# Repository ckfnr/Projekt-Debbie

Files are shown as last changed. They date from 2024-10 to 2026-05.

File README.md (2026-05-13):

# **Debbie**

<p align="center">
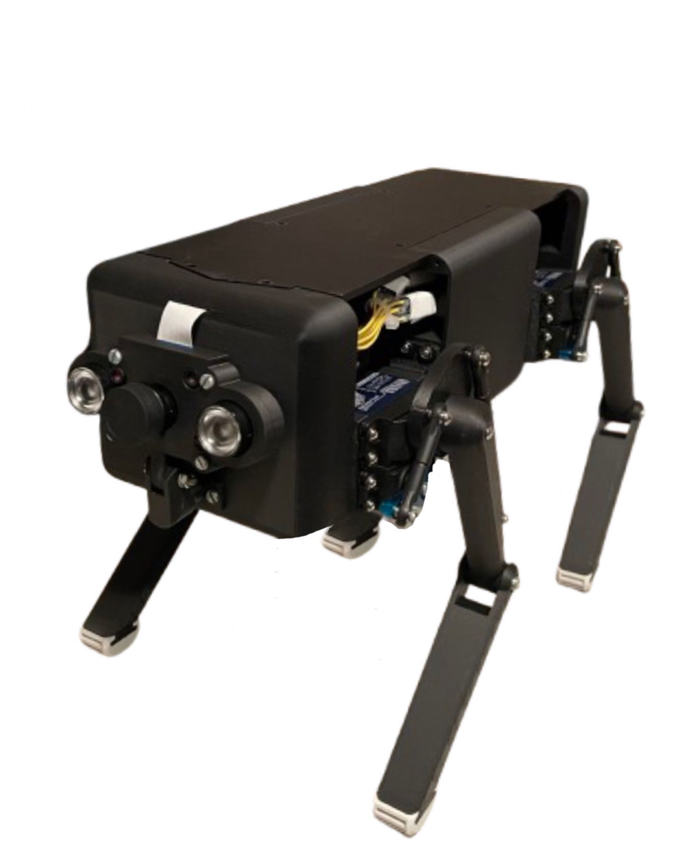
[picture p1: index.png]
  
</p>

## 📜 **Description**
_Debbie_ is a straightforward yet fascinating quadrupedal robot designed with simplicity in mind. Stay tuned for ongoing enhancements!<br>
💰Project sponsored by _The Schrack Technik Group_

## 📝 Incoming
- Detailed documentation
- Remote control

## ⚙️ Accessories
- [Remote Control](https://github.com/AJ-Holzer/Debbie-V1---Keyboard)

## 👀 Check out
### ⚙ Hardware-Development, assisting Programmer, Design & Organization:
- [Cesario Kufner](https://github.com/ckfnr)
### 💻 Programming:
- [AJ-Holzer](https://github.com/AJ-Holzer)
### Documentation & assisting in Design:
- [Louati Momen](https://github.com/louatimomen)
### Huge Shoutout to [Mr. Hühnchen](https://github.com/MrHuehnchen)! 🎉
A massive thank you to __Mr. Hühnchen__ for calculating __all the computations__ for Debbie!<br>
💡⚡

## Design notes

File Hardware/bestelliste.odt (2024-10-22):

Bestellliste

Servomotoren x 12

link: https://amzn.eu/d/aAuCnyE

preis: 290,28 euro

Akku x 9

link: https://www.conrad.at/de/p/eve-inr18650-33v-spezial-akku-18650-flat-top-hochstromfaehig-li-ion-3-6-v-3200-mah-2618353.html

preis: 1107,25 euro

Battery spot welder x 1

link: https://amzn.eu/d/flXxwCL

preis: 50.42 euro

Gyroskop-Sensor x 1

link: https://amzn.eu/d/5GvUgRg

preis: 9.06 euro

Google coral AI accelerator x 1

link: https://amzn.eu/d/iyRLuVV

preis: 91.70 euro

Raspberry 4b x1

link: https: https://amzn.eu/d/8mECIaa

preis: 86,71 euro

Raspberry pi Camera x1

link: https://nl.aliexpress.com/item/32881466491.html?spm=a2g0s.9042311.0.0.320c4c4dXaaHcX

preis: 11.59 euro

Schrauben-Set x1

link: https://amzn.eu/d/2u4cu5q

preis: 25.70 euro

PCB-protection circuit x1

link: https://amzn.eu/d/9HBHvqb

preis: 11.09 euro

Servo Driver x1

link: https://amzn.eu/d/9qbfp5R

preis: 7.04 euro

Rod ends x1

link: https://amzn.eu/d/5am6awO

preis: 16.66 euro

684ZZ Kugellager x2

link: https://amzn.eu/d/8TTudFz

preis: 11,06 euro

Servo Horn 25T x2

link: https://amzn.eu/d/a9BvvhE

preis: 24,38 euro

Schalter x1

link: https://www.soselectronic.com/de-de/products/marquardt/1830-3112-468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

preis: 3,33 euro

HDMI-Verlängerung x1

https://www.amazon.de/gp/product/B09PYWKCWW/ref=ppx_yo_dt_b_asin_title_o01_s00?ie=UTF8&th=1

preis: 10,07 euro

USB-Verlängerung x1

https://www.amazon.de/dp/B083Y2DR9Z?ref=ppx_yo2ov_dt_b_fed_asin_title

preis: 10,07 euro

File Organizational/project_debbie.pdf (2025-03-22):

## Project Debbie

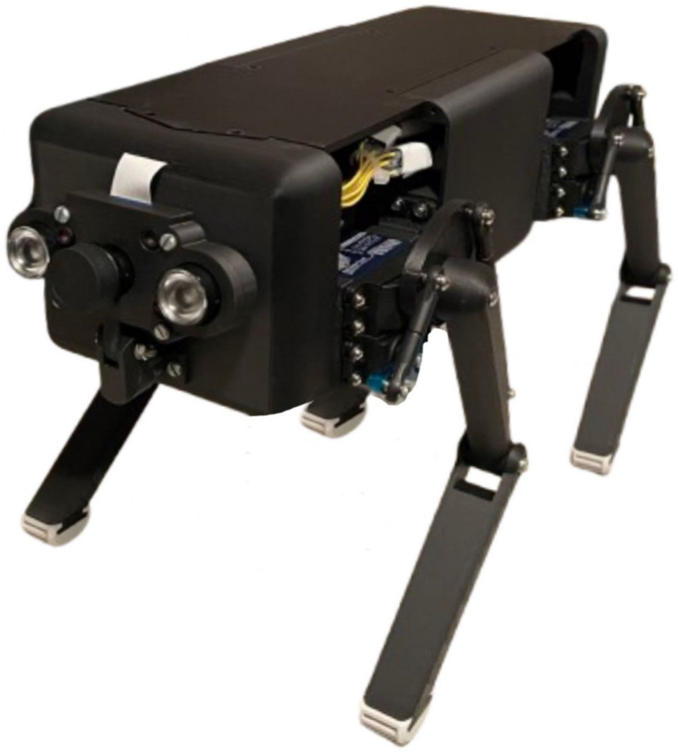
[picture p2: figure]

Cesario Kufner
Momen Louati
AJ Holzer
Prof. Ing. Michael Wagner

15.01.2025

table of contents

### Parts and Assembly

Production of Parts

3d-printed Parts

The parts of Debbie are mainly 3D printed. There are 3 parts that are laser cut, which are the bottom plate, midde plate and upper plate. Below is the name of the STL file to be 3d printed, the amount of parts that has to be printed and their infill density.
We strongly recommend these parts to be printed with carbon filament. All of these parts are found within the respective Folder inside the „Hardware“-folder
Battery:
Name | Amount | Infill
case.stl | x3 | 70%
cover.stl | x2 | 100%
cover_closed.stl | x1 | 100%

Body:

Name | Amount | Infill
back.stl | x1 | 70%
bolt.stl | x4 | 100%
front.stl | x1 | 70%
lower_back_plate_switch_charger.stl | x1 | 100%
side.stl | x2 | 70%
upper_back_plate_usb_hdmi.stl | x1 | 100%
Camera:
Name | Amount | Infill
holder.stl | x1 | 100%
holder_base.stl | x1 | 100%
holder_top.stl | x1 | 100%

Legs:

Name | Amount | Infill
lower_leg_left.stl | x2 | 70%
lower_leg_right.stl | x2 | 70%
rubber_tip.stl | x4 | 40%
thigh.stl | x4 | 50%

Mounts:

Name | Amount | Infill
distance_rod.stl | x4 | 100%
servoarm_left.stl | x2 | 100%
servoarm_right.stl | x2 | 100%
servoholder_left.stl | x2 | 100%
servoholder_left_B.stl | x2 | 100%
servoholder_right.stl | x2 | 100%
servoholder_right_B.stl | x2 | 100%

Laser-cut Parts
As mentioned before, there are 3 laser-cut parts. These are the following: bottom plate, midde plate and upper plate.
All of these parts are to be lasered with 3mm plastic. Whatever color you use depends on your personal preference.

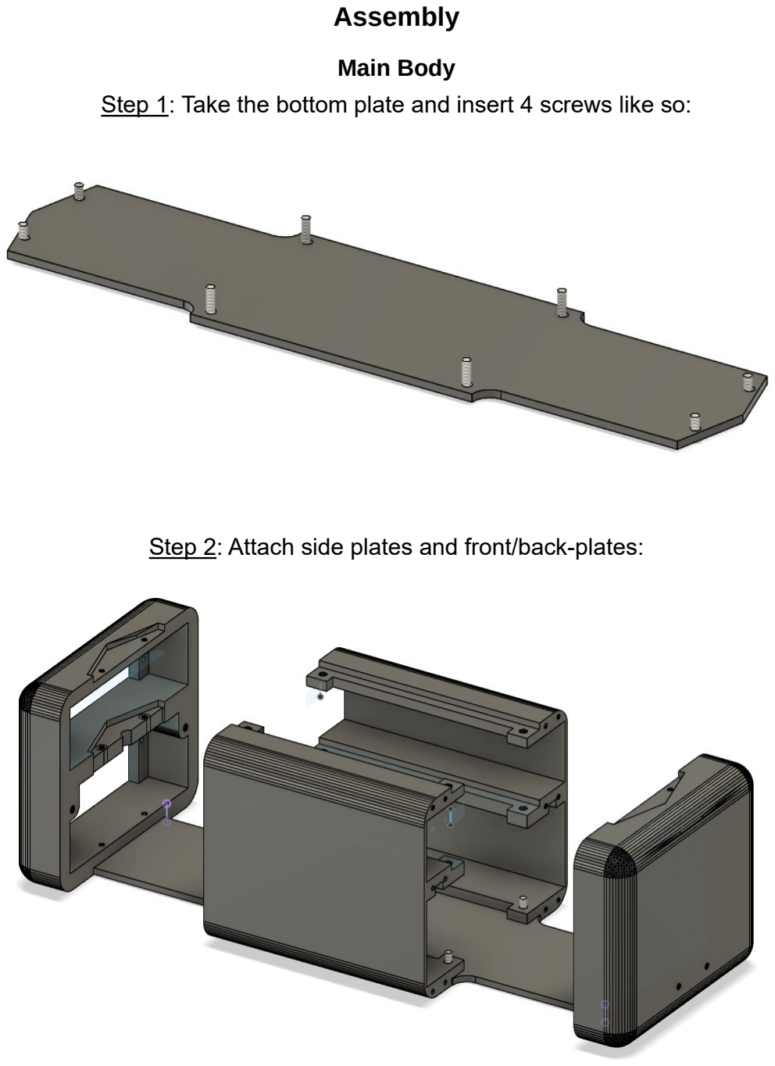
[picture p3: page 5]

Assembly

Main Body
Step 1: Take the bottom plate and insert 4 screws like so:
Step 2: Attach side plates and front/back-plates:

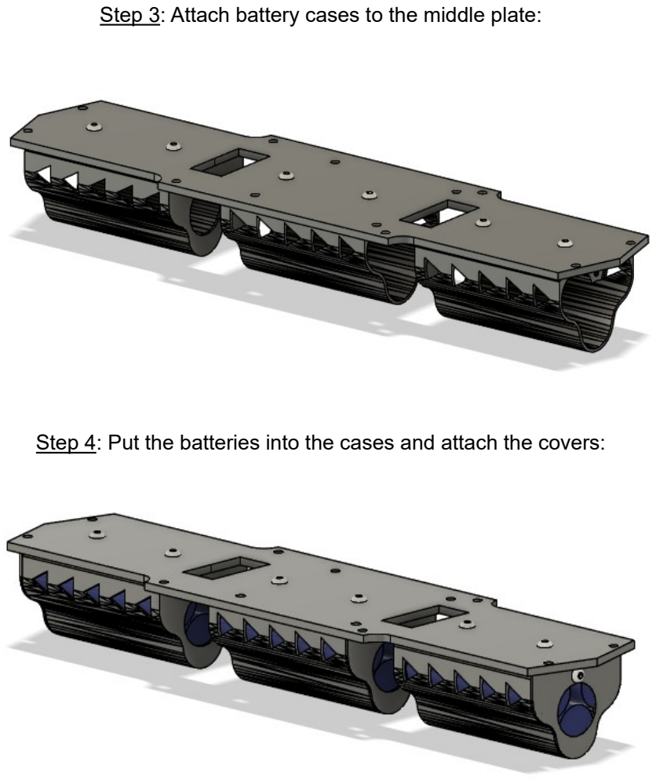
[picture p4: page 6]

Step 3: Attach battery cases to the middle plate:
Step 4: Put the batteries into the cases and attach the covers:

Wire the batterys, BMS, switch and step-down according to this diagram:

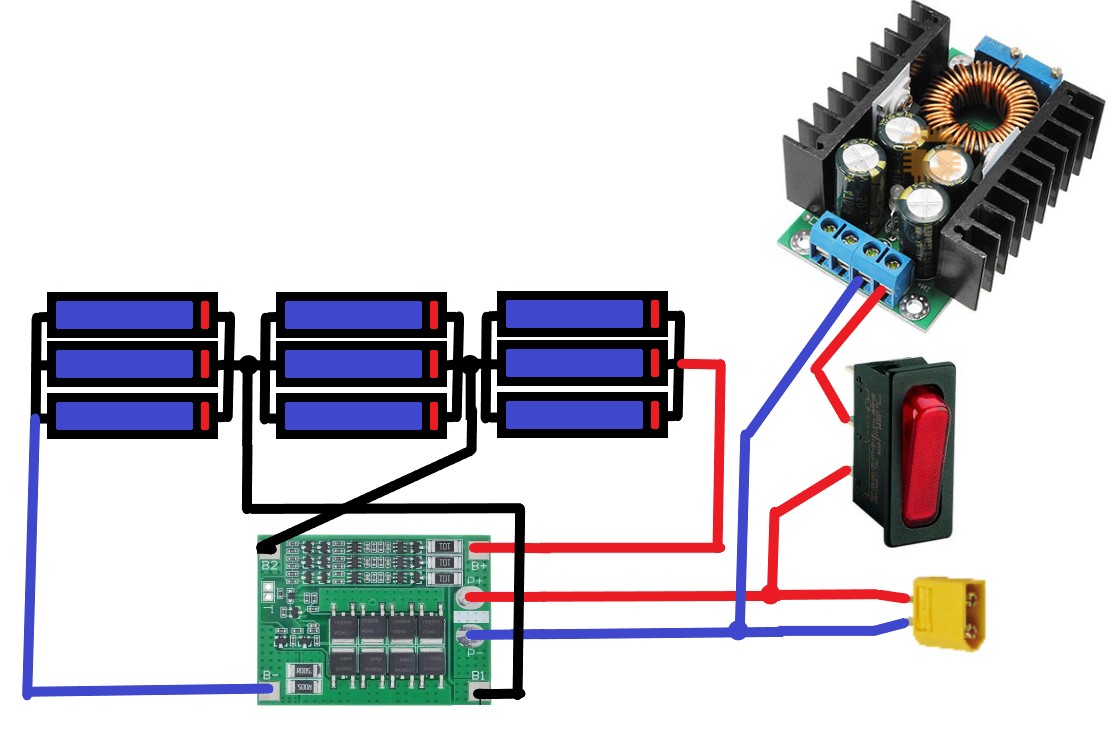
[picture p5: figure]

Dont forget to route the wires that lead to the step-down in a way that they can go through the opening of the middle plate in the front. The step-down will act as the main power source for all components later and must be set to an output of 5 volts. Put the ampere limiter to the lowest so that the full amps can be used. The XT-60 and the Switch will be at the back, so make the wires long enough for that to be possible.

Step 5: Attach the Raspberry pi to the Middle plate:

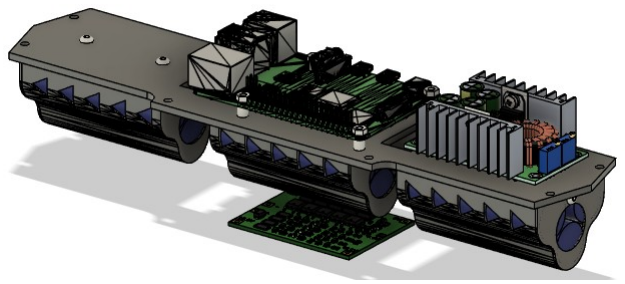
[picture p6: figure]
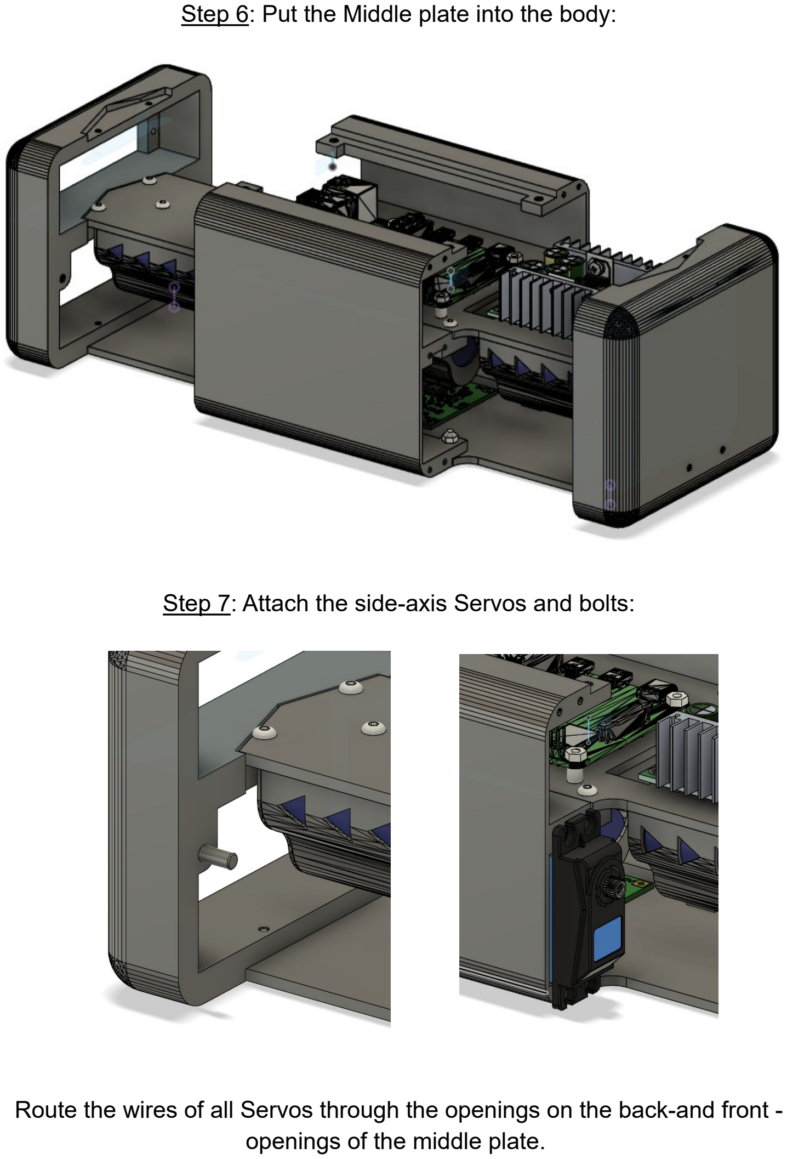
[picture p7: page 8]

Step 6: Put the Middle plate into the body:
Step 7: Attach the side-axis Servos and bolts:

Route the wires of all Servos through the openings on the back-and front -openings of the middle plate.

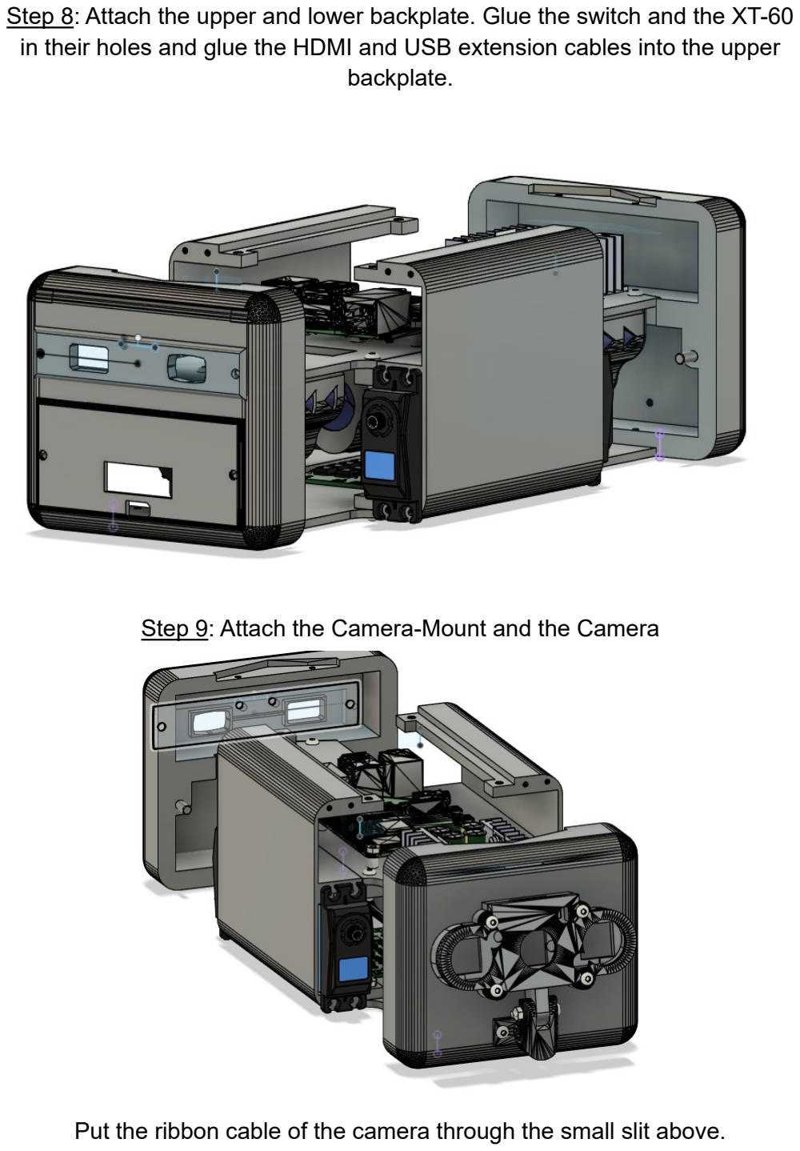
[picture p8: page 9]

Step 8: Attach the upper and lower backplate. Glue the switch and the XT-60 in their holes and glue the HDMI and USB extension cables into the upper backplate.
Step 9: Attach the Camera-Mount and the Camera

Put the ribbon cable of the camera through the small slit above.

Legs

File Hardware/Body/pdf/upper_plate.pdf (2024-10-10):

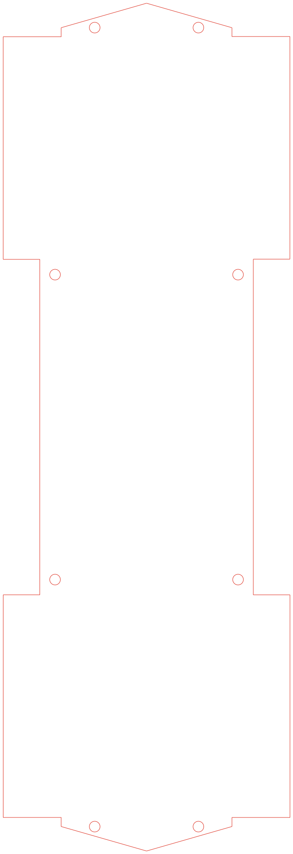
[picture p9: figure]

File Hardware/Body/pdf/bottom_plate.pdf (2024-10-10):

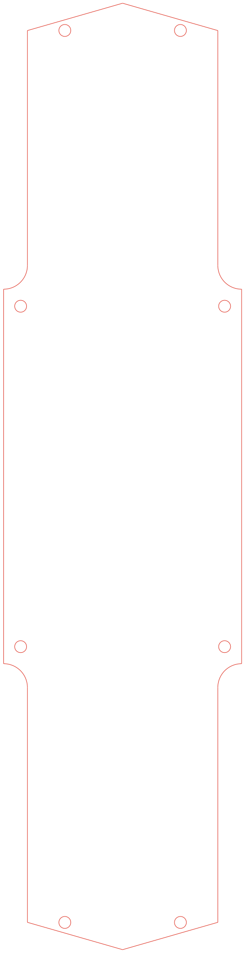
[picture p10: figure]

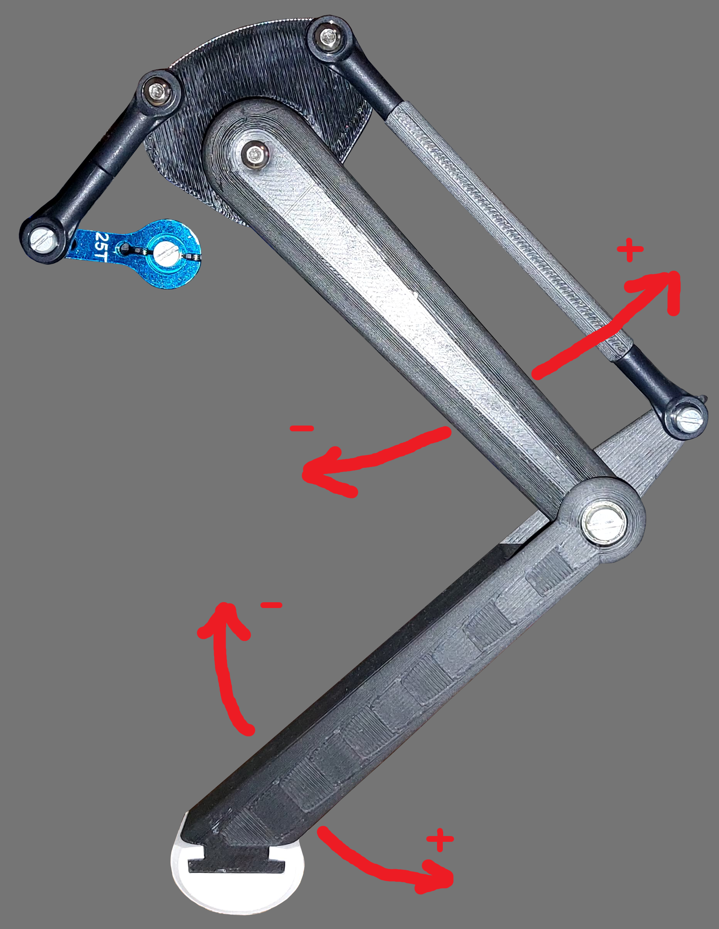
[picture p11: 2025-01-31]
Images/Leg_lb_control.png

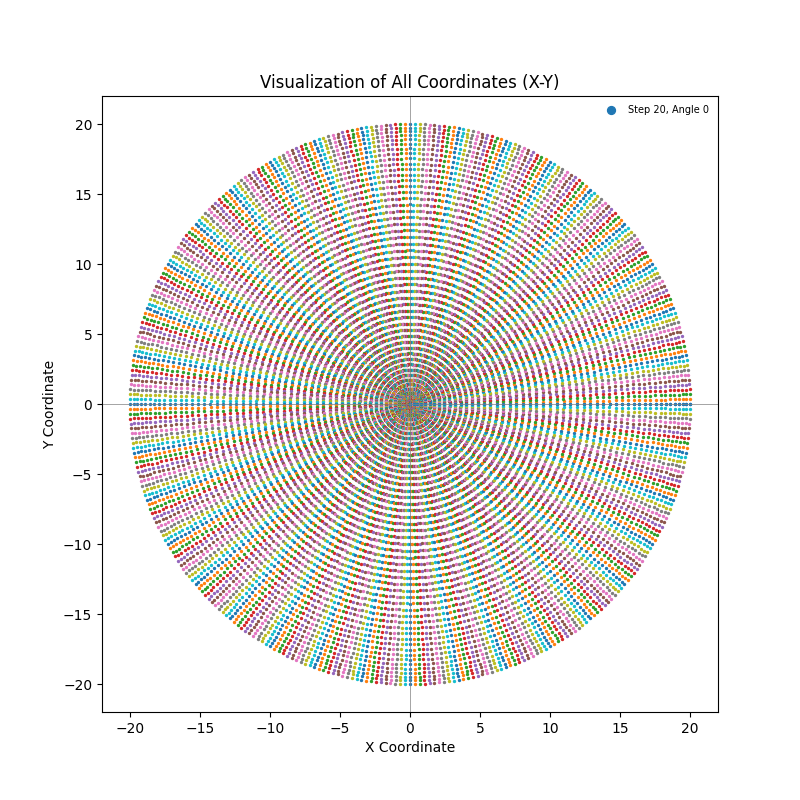
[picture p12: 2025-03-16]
Images/Points_20_xy.png

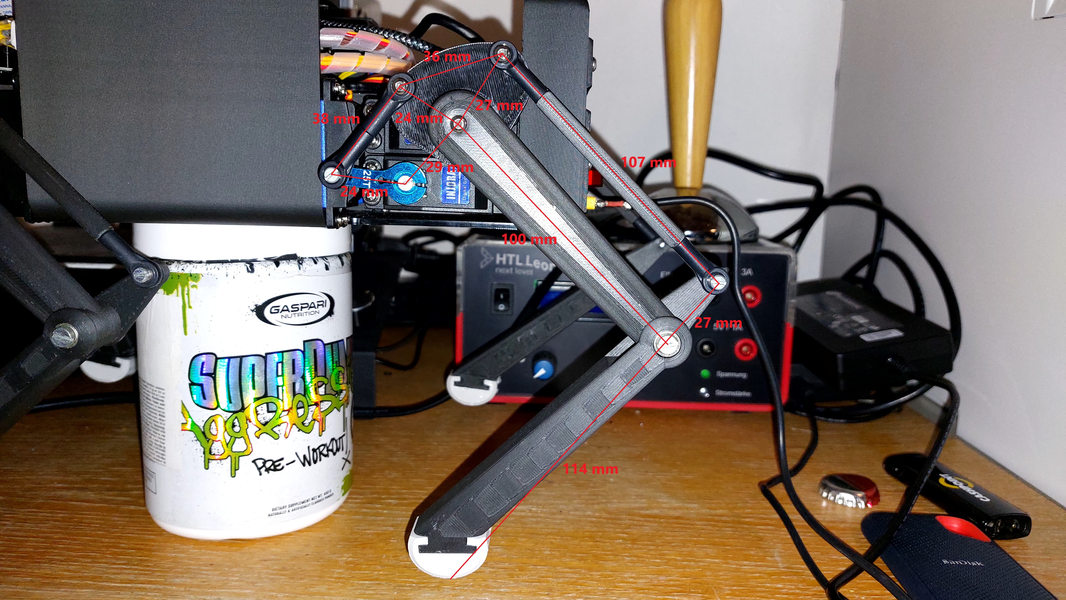
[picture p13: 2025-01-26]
Images/Leg_rb_view.jpg

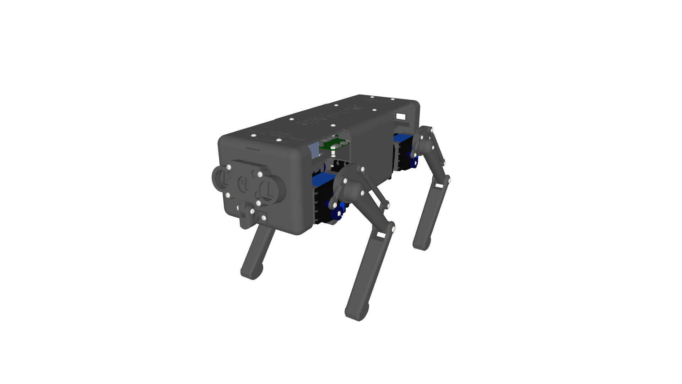
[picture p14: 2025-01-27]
Images/front_view_1.png

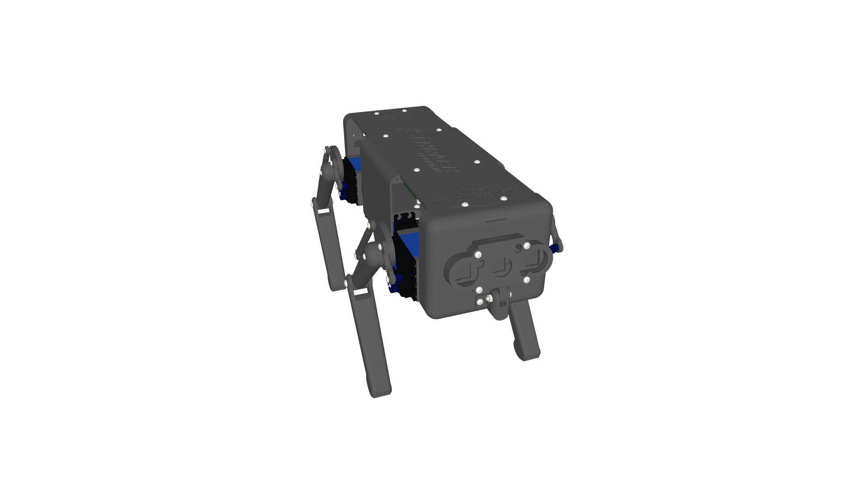
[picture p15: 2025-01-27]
Images/front_view_2.png

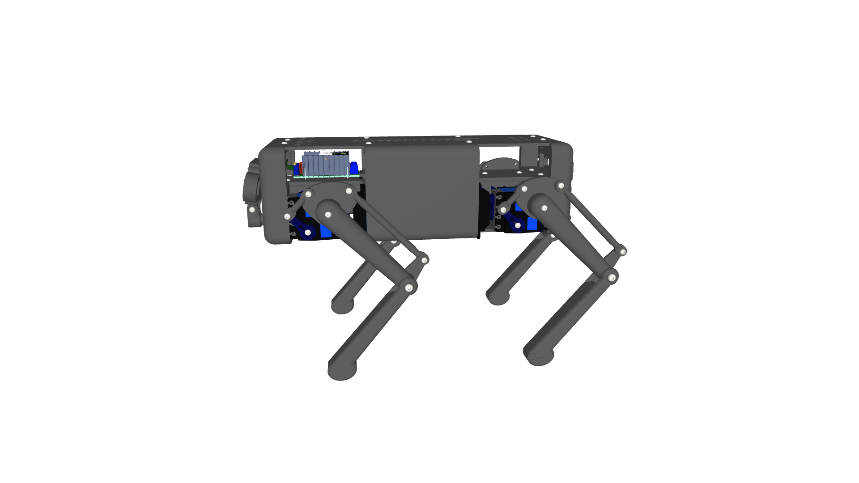
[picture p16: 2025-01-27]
Images/side_view_2.png

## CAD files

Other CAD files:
Hardware/Battery/stl/cover.stl
Hardware/Body/stl/lower_back_plate_switch_charger.stl
Hardware/Camera/stl/holder_base.stl
Hardware/Legs/stl/lower_leg_left_new.stl
Hardware/Mounts/stl/distance_rod.stl
Hardware/Battery/stl/case.stl
Hardware/Body/stl/side.stl
Hardware/Camera/stl/holder_top.stl
Hardware/Legs/stl/lower_leg_right_new.stl
Hardware/Mounts/stl/servoarm_left.stl
Hardware/Battery/stl/cover_closed.stl
Hardware/Camera/stl/holder.stl
Hardware/Legs/stl/rubber_tip.stl
Hardware/Mounts/stl/servoarm_right.stl
Hardware/Body/stl/back.stl
Hardware/Legs/stl/lower_leg_left.stl
Hardware/Mounts/stl/servoholder_right.stl
Hardware/Body/stl/front.stl
Hardware/Battery/f3d/case.f3d
Hardware/Battery/f3d/cover_closed.f3d
Hardware/Body/f3d/duebel v1.f3d
Hardware/Body/f3d/front.f3d
Hardware/Body/f3d/heck.f3d
Hardware/Body/f3d/middle_plate.f3d
Hardware/Body/f3d/obere heckplatte v6.f3d
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

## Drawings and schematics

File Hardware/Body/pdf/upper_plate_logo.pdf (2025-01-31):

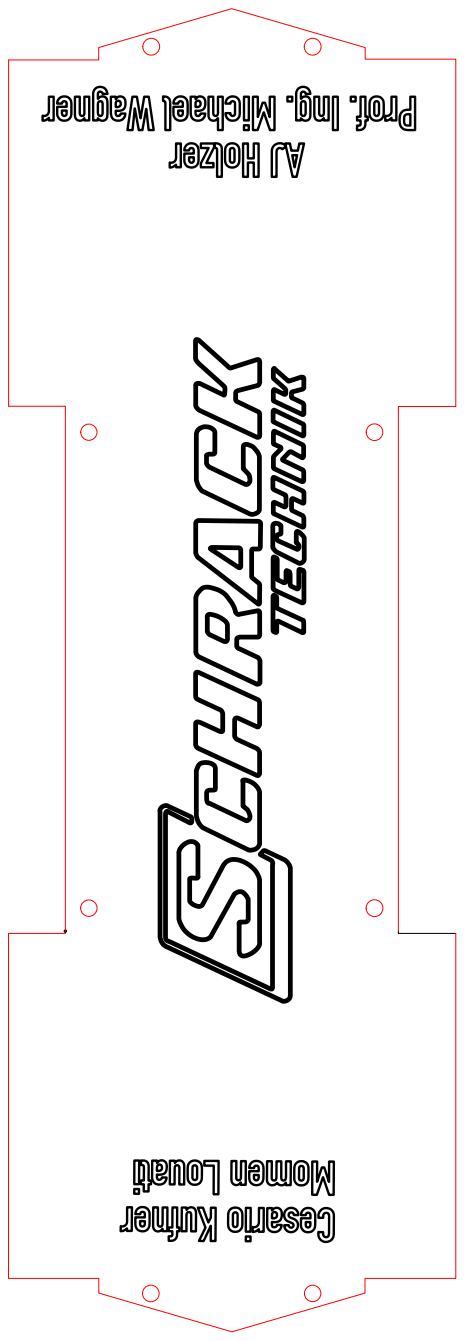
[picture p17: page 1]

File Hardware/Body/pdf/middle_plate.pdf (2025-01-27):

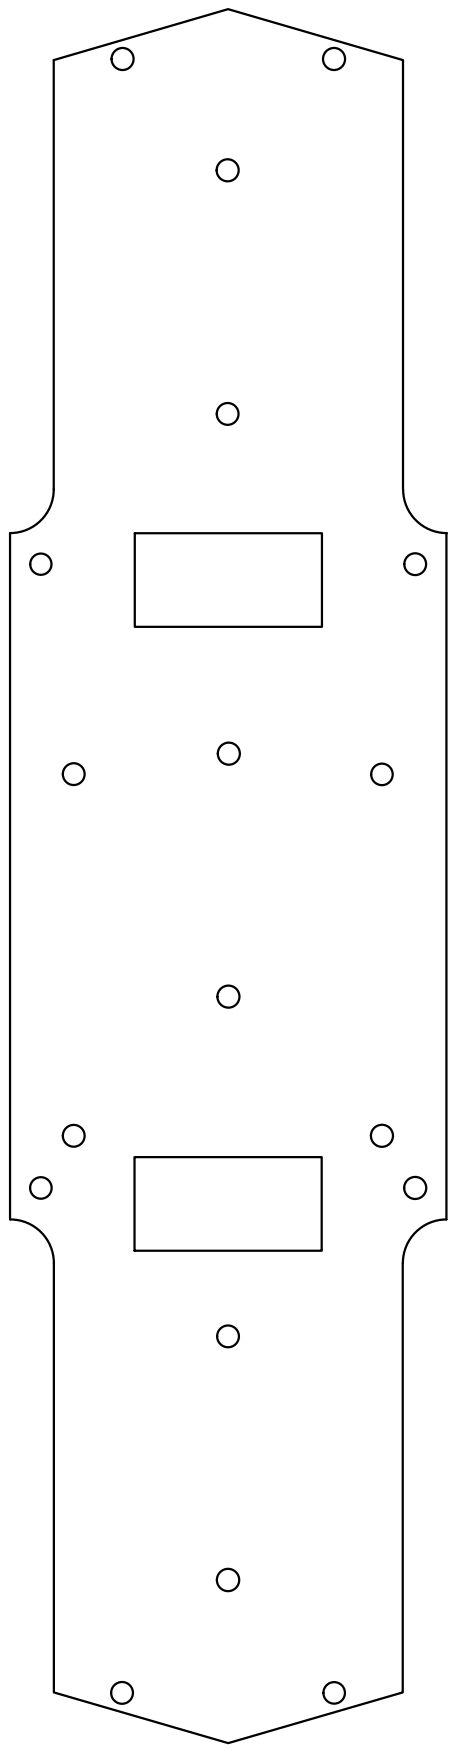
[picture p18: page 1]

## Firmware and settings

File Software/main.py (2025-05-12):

import time
from typing import Optional, Literal

# Classes
from env.classes.movement import Movement
from env.classes.controller import Controller

# Func
from env.func.DEBUG import dprint
from env.func.autostart import startup_script

# Config
from env.config import config

def run_input_thread(mvmnt: Movement) -> None:
    """Thread to handle input from the controller."""
    while True:
        try:
            # Initialize the reset flag to True
            reset: bool = True  # Flag to indicate if the reset command has already been executed

            # Initialize the controller
            ctrllr = Controller()

            # Main loop to get input from the controller and execute corresponding movement
            while True:
                # Get input from the controller
                input_command: Optional[Literal["step-backwards", "step-forwards", "turn-left", "turn-right", "sidestep-left", "sidestep-right", "lower", "lift", "normal", "RESET", "HEARTBEAT"]] = ctrllr.last_input
                elapsed_time_since_heartbeat: float = time.time() - (ctrllr._last_heartbeat if ctrllr._last_heartbeat else 0)

                if elapsed_time_since_heartbeat > config.max_heartbeat_interval:
                    dprint(f"{config.color_yellow}No heartbeat received for {elapsed_time_since_heartbeat:.2f} second(s), skipping next movement...{config.color_reset}")
                elif input_command is None:
                    dprint(f"{config.color_yellow}[ NOTE ] No input received, waiting...{config.color_reset}")
                elif input_command == "RESET" and reset:
                    dprint(f"{config.color_yellow}Received RESET command, stopping all movements...{config.color_reset}")
                    mvmnt.interrupt_movements()
                    mvmnt.normalize_all_legs(duration_s=0.3)                                # Normalize all legs to their default position
                    reset = False                                                           # Set the reset flag to True to prevent multiple resets
                elif input_command in mvmnt.function_map:
                    mvmnt.function_map[input_command]()
                    reset = True                                                            # Reset the reset flag after executing the command
                    dprint(f"{config.color_green}Finished executing command: {input_command}")

                # If the command is not valid, print an error message
                if not reset and input_command != "RESET":
                    dprint(f"{config.color_red}Invalid command received: {input_command}{config.color_reset}")

                time.sleep(0.1)
        except Exception as e:
            dprint(f"{config.color_red}Error in input thread; Restarting! Error: {e}{config.color_reset}")

            # Attempt to close the controller socket if it exists
            if ctrllr and ctrllr.sock:
                ctrllr.sock.close()  # Close the socket to free the port
        
            time.sleep(1)  # Sleep for a second before restarting the thread

def main() -> None:
    """Main function."""
    if config.debug:
        dprint(f"{config.color_green}Debug mode on!{config.color_reset}")

    mvmnt = Movement()

    # Execute startup script
    startup_script(mvmnt=mvmnt)
    run_input_thread(mvmnt=mvmnt)  # Start the input thread

if __name__ == "__main__": main()

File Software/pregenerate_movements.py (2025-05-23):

import numpy

# Classes
from env.classes.db import DB
from env.classes.calculator import Calculator
from env.classes.Classes import Coordinate

def main() -> None:
    db = DB()
    clctr = Calculator()

    clctr.pregenerate_coordinates(frm = 1.0, to=20.0, step=0.1)

    for step_width in numpy.arange(1.0, 20.1, 0.1):
        print(f"Saving coordinates for step width {step_width:.1f}...")
        for angle in range(360):
            coords: list[Coordinate] = clctr.get_coordinates(step_width=round(step_width, 1), angle=angle)
            for coord in coords:
                db.store_coordinates(step_width=round(float(step_width), 1), angle=angle, coord=coord)
    db.save()

    print("Done!")

if __name__ == "__main__": main()

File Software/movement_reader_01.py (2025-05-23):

from typing import Any


movement_file: str = "TEST_standup.mmt"

# Load data
with open(movement_file, "r", encoding="UTF-8") as f:
    data = f.read()

converted_data: list[str] = [i.strip() for i in data.split("\n") if i and not i.startswith("//")]

# Check if there are any errors in the file
for idx, line in enumerate(converted_data, start=1):
    if not line.endswith(";"):
        raise Exception(f"Line {idx} must end with ';'!")

# Convert to instructions
instructions: list[dict[str, Any]] = []
current_block: dict[str, str | float | dict[str, dict[str, float]]] = {}

for instruction in converted_data:
    instruction = instruction.rstrip(";")  # Remove the trailing semicolon for easier parsing

    if instruction == "MOVEMENT-START":
        current_block = {"type": "MOVEMENT", "duration": 0, "vectors": {}}

    elif instruction == "MOVEMENT-JOIN":
        if current_block:  # Only append if there is an active block
            # Check if any part of the instruction is not ok
            if not isinstance(current_block["type"], str):                  raise ValueError(f"Wrong type for 'type'! Got '{type(current_block["type"])}'; expected 'str'!")
            if not isinstance(current_block["duration"], float):            raise ValueError(f"Wrong type for 'duration'! Got '{type(current_block["duration"])}; expected 'float'!")
            if not isinstance(current_block["vectors"], dict):              raise ValueError(f"Wrong type for 'vectors'! Got '{type(current_block["vectors"])}; expected 'dict'!")
            if current_block["type"] != "MOVEMENT":                         raise ValueError(f"The value for 'type' is not 'MOVEMENT'! Got {current_block["type"]} instead.")
            if current_block["duration"] <= 0:                              raise ValueError(f"Wrong type for 'duration'! Got '{type(current_block["duration"])}; expected 'float'!")
            if len(current_block["vectors"]) != 4:                          raise ValueError(f"Too many values for 'vectors'! Got {len(current_block['vectors'])}; expected 4!")
            if ["rf", "rb", "lf", "lb"] - current_block["vectors"].keys():  raise ValueError(f"Wrong values for 'vectors'! Got '{current_block["vectors"]}'; expected ['rf', 'rb', 'lf', 'lb']!")

            instructions.append(current_block)
            current_block = {}

    elif instruction.startswith("seconds="):
        current_block["duration"] = float(instruction.split("=")[1])

    elif ":" in instruction:
        if not isinstance(current_block["vectors"], dict):
            raise ValueError("Vectors must be a dict!")

        part, coords = instruction.split(": ")
        coord_values = {k: float(v) for k, v in (pair.split("=") for pair in coords.split(", "))}
        current_block["vectors"][part] = coord_values

# Check if the last instruction was parsed successfully
if current_block:
    raise Exception("The last instruction was not parsed successfully! Maybe forgot 'MOVEMENT-JOIN;'?")

print(f"{len(instructions)} instructions parsed")
# for block in instructions:
#     pprint(block)

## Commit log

2024-10-09 front gefixed
    [front.stl]
2024-10-10 case verbessert
    [case.stl]
2024-10-15 seitenteil
    fortnite
    [seitenteilx2.stl]
2024-10-15 verbesserungen bei körper
    [front.f3d, front.stl, heck.f3d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]
2024-10-16 dateien gelöscht
    [heck.f3d, seitenteilx2.f3d]
2024-10-16 platten als f3d
    [mittelplatte v2.f3d, oberplatte.f3d, unterplatte v1.f3d]
2024-10-16 akku case
    [case.stl, casex3.stl, deckel.stl]
2024-10-16 Unterschenkel neu
    [Unterschenkel v3 v1.f3d, Unterschenkel v3 v1.stl, Unterschenkel_2x2.stl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]
2024-10-16 änderung
    [front.stl]
2024-10-18 front & heck verbessert
    [front v0.stl, front.f3d, front.stl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]
2024-10-21 unterplatte hinten
    [untere heckplatte.f3d, untere heckplatte.stl]
2024-11-05 obere und untere heckplatte bearbeitet
    [obere heckplatte v5.stl, obere heckplatte.stl, untere heckplatte v1.stl]
2024-12-03 Ordner umorganisiert
    [Unterschenkel v3 v1.f3d, abstandhalterx4.stl, case.stl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]
2025-01-12 übersetzt
    [Unterschenkel v3 v1.f3d, abstandhalterx4.stl, case.stl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]
2025-01-25 oberplatte mit logo
    [oberplatte_logo.f3d]
2025-01-31 Uploaded leg control image
2025-01-31 upper plate
2025-02-08 reorganized test camera
2025-02-08 updated test camera
2025-02-08 uploaded test camera
2025-02-08 updated test camera 2
2025-02-08 update test camera 2
2025-04-03 lower leg update
    [Unterschenkel v3 v1 v16.f3d, lower_leg_left.stl, lower_leg_left_new.stl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]
2025-05-23 Add initial implementation of movement control and configuration
    - Introduced count_lines.py for counting lines of code in the project.
    - Added drawing.drawio for visual representation of the system architecture.
    - Created config-BACKUP.py with configuration settings for the movement system.
    - Implemented calculations.py for mathematical operations related to movement.
    - Developed force_reset_angles_to_90.py to reset servo angles to 90 degrees.
    - Created move_single_01.py for single servo movement control.
    - Implemented movement_reader_01.py to parse movement instructions from files.
    - Added pregenerate_movements.py for generating and storing movement coordinates.
    - Developed present.py for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
    [move_single_01.py, movement_reader_01.py, pregenerate_movements.py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]
